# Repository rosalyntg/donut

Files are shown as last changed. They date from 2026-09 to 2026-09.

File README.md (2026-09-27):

# Donut

A simple ring light designed for a StereoZoom 4 microscope.

## Basic description

A ring light with adjustable brightness (potentiometer knob) driven by a MP3383 LED driver. It has 60 LEDs on them arranged in a circular pattern to give good lighting.

## Images

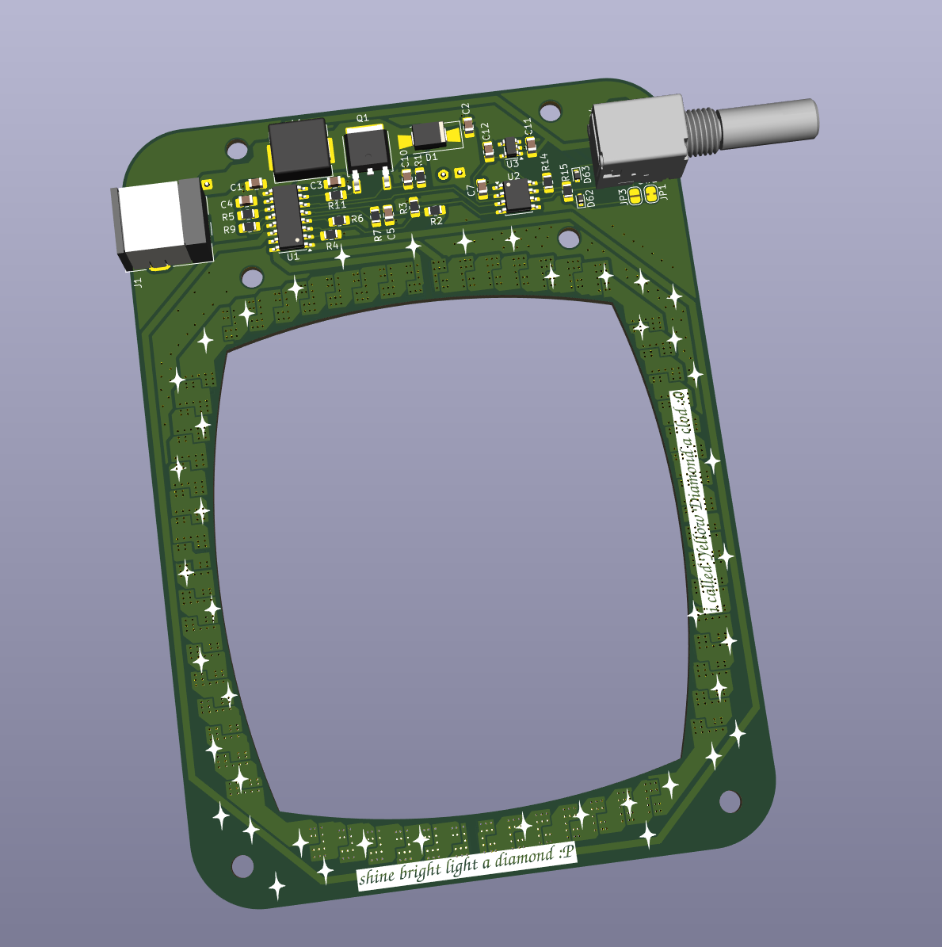
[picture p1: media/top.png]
Donut Top Ring Light

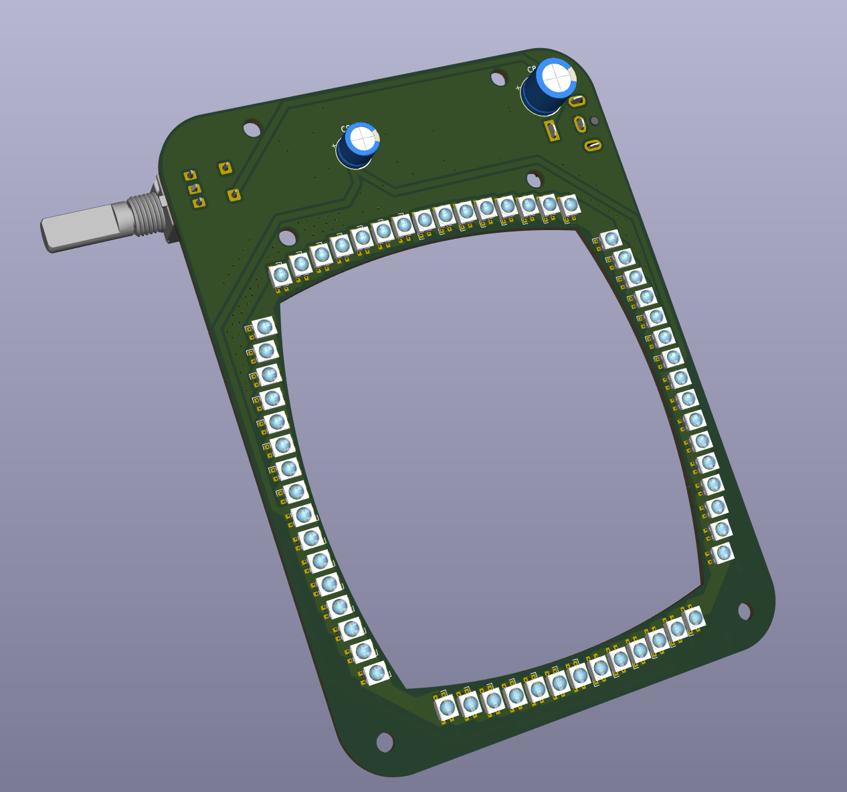
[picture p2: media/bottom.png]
Donut Bottom Ring Light


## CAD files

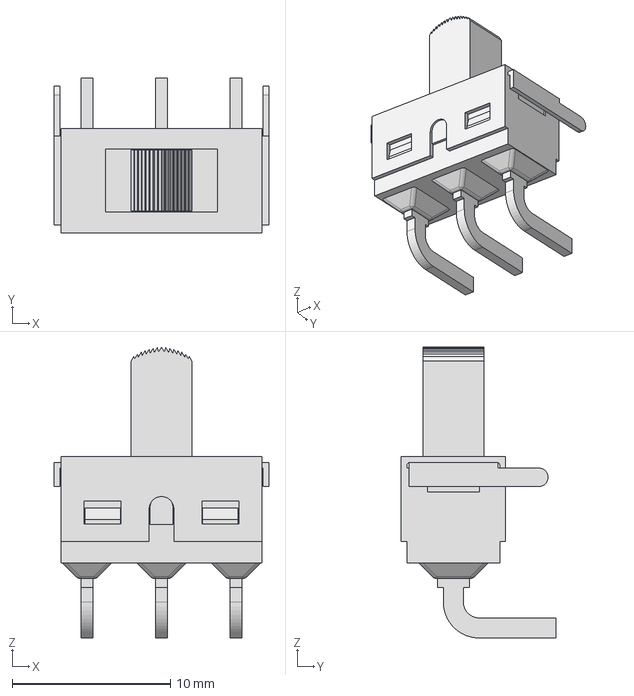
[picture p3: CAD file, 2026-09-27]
3d/141_500SSPxS2M6xEA.stp
13.6 x 9.78 x 18.4 mm

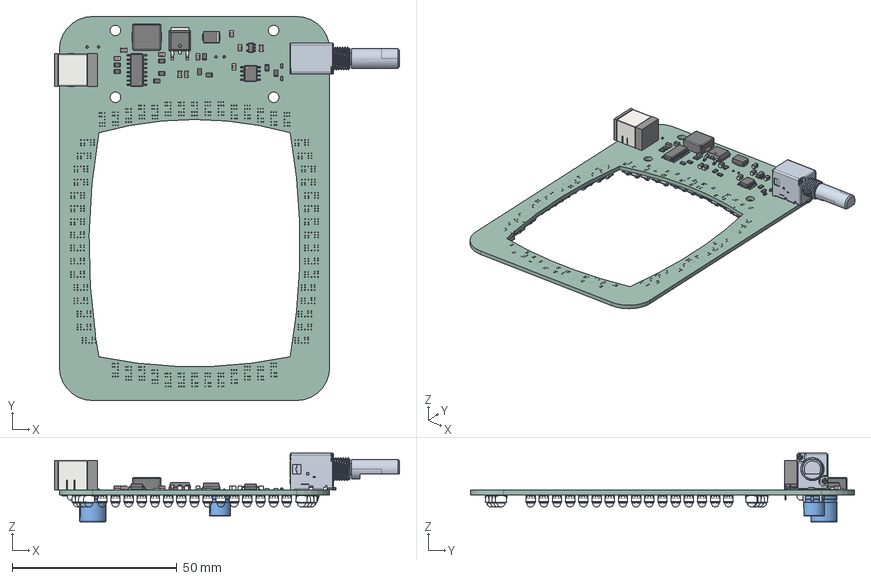
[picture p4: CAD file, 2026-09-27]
donut/donut.step
104.7 x 116.5 x 20.8 mm
R_0805_2012Metric x 10
SOT-23-5
932d09b3-9c39-11ed-93f0-dde97e994e83_part
932d09b4-9c39-11ed-93f0-dde97e994e83_part
932d09b5-9c39-11ed-93f0-dde97e994e83_part
BarrelJack_CUI_PJ-063AH_Horizontal
C_0805_2012Metric x 10
L_APV_APH0840
P091S-FC20_SW0001
D_SOD_523 x 2
SOIC-8_3.9x4.9mm_P1.27mm
D_SMB
SOIC-16_3.9x9.9mm_P1.27mm
IN-P36ATEUW.56 x 60
CP_Radial_D63mm_P250mm
CP_Radial_D80mm_P350mm
donut-unsaved-export-lDOu0E_PCB

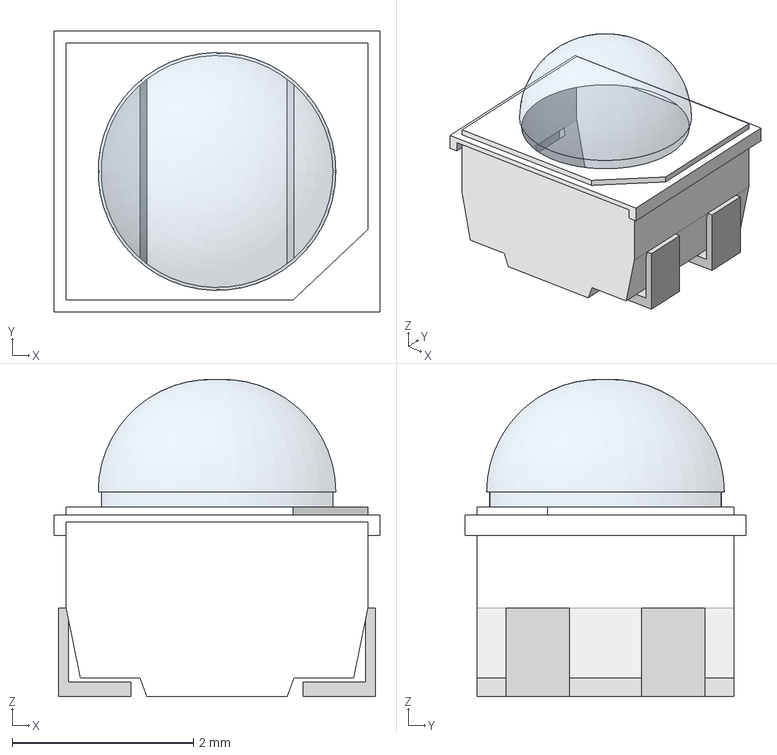
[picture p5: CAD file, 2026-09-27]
3d/IN-P36ATEUW.56.stp
3.60 x 3.10 x 3.50 mm

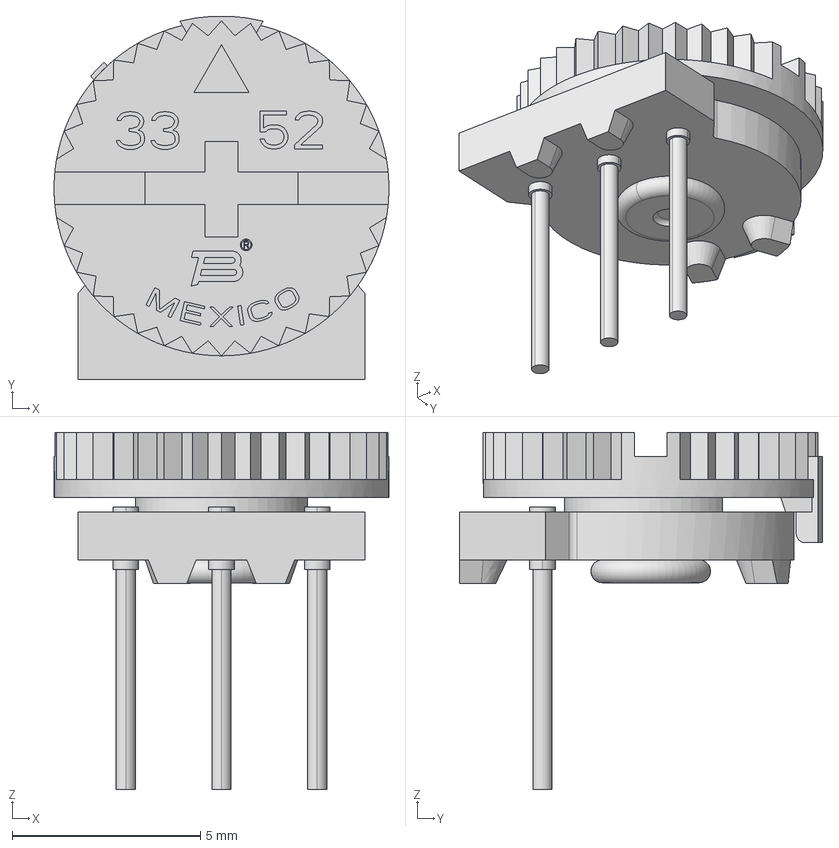
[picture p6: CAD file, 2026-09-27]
3d/3352T-1.stp
8.89 x 9.65 x 9.47 mm

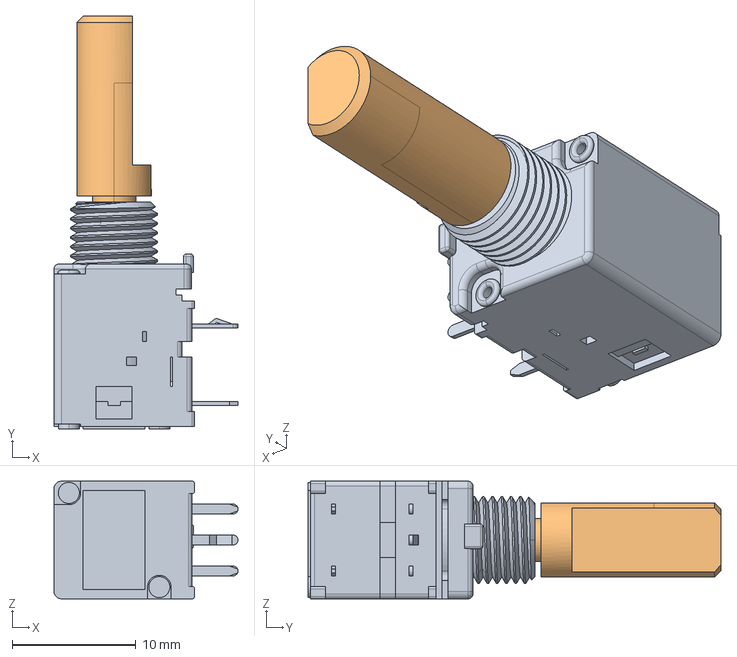
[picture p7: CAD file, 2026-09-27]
3d/P091S-FC20BR10K.stp
14.9 x 33.3 x 9.50 mm

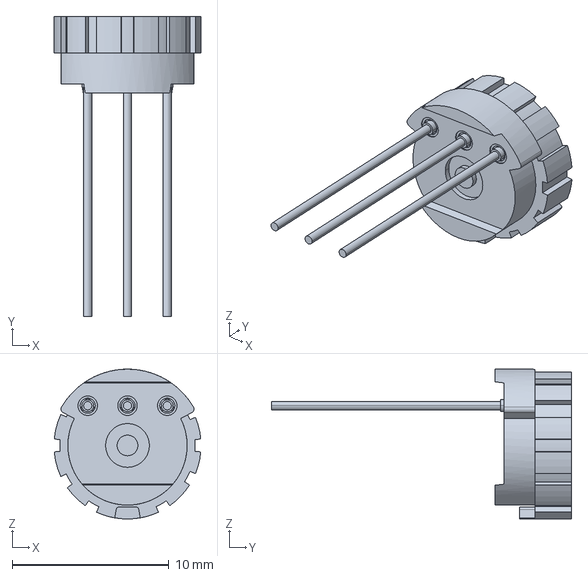
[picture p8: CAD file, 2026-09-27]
3d/TT-91A.stp
9.36 x 19.2 x 9.57 mm

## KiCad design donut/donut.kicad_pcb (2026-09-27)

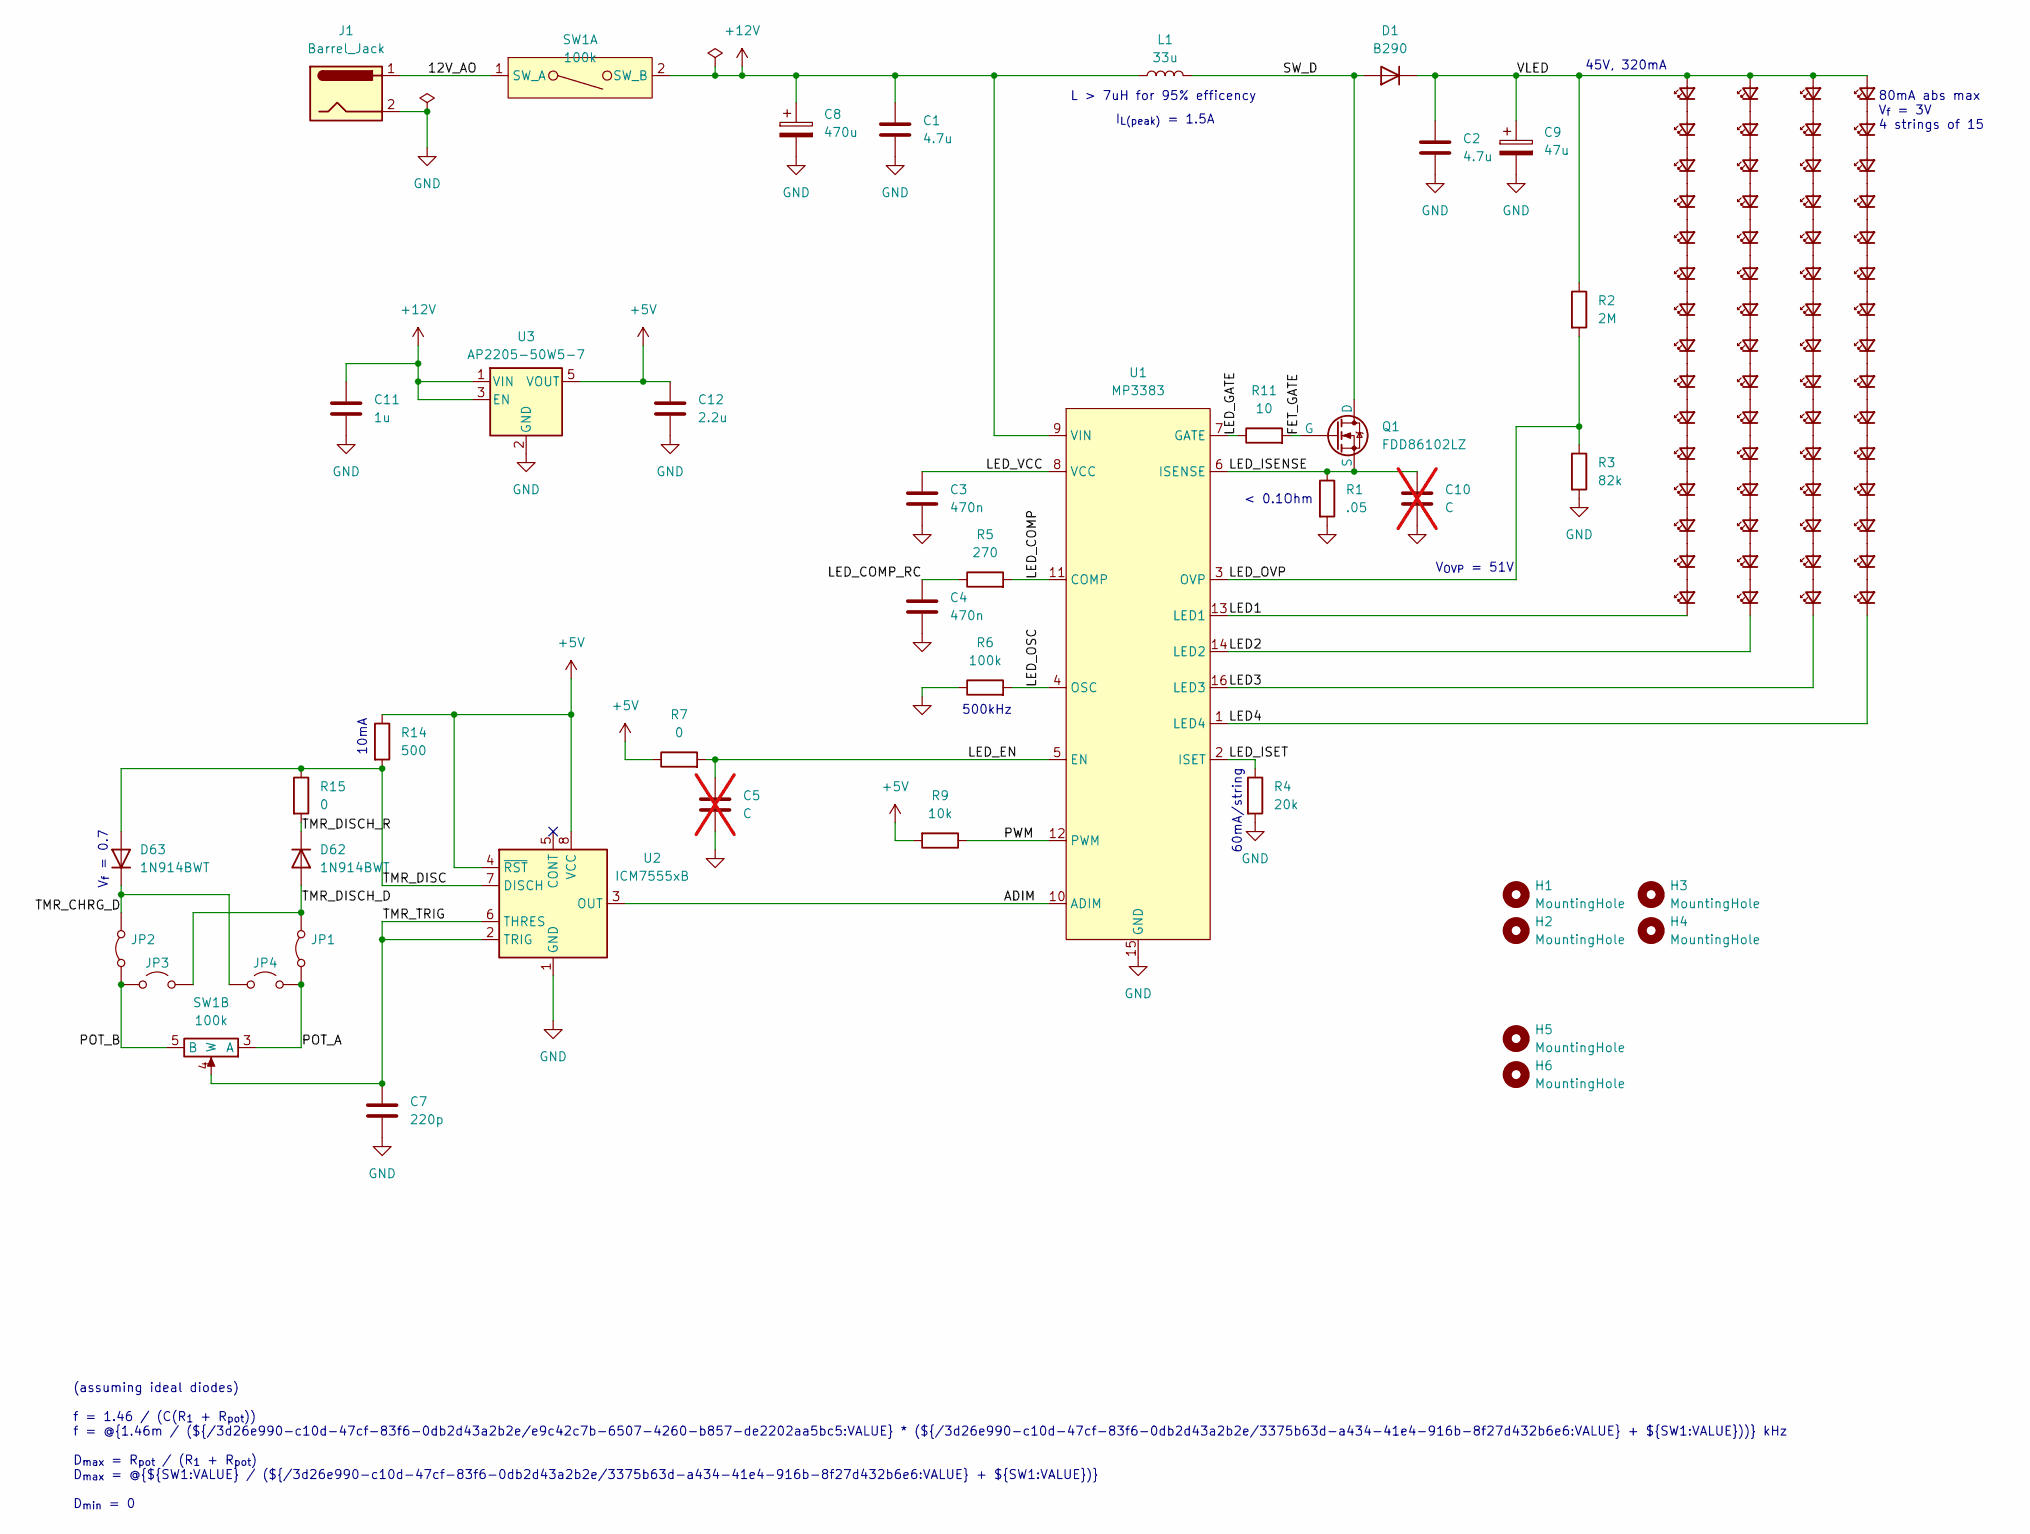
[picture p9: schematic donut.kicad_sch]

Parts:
C1, C2: 4.7u; C_0805_2012Metric_Pad1.18x1.45mm_HandSolder; Manufacturer Part Number GRT21BR61H475KE13L; Digikey Part Number 490-12394-1-ND
C3, C4: 470n; C_0805_2012Metric_Pad1.18x1.45mm_HandSolder
C5, C10: C; C_0805_2012Metric_Pad1.18x1.45mm_HandSolder; not fitted
C7: 220p; C_0805_2012Metric_Pad1.18x1.45mm_HandSolder
C8: 470u; CP_Radial_D8.0mm_P3.50mm; Manufacturer Part Number 860020374012; Digikey Part Number 732-8799-1-ND
C9: 47u; CP_Radial_D6.3mm_P2.50mm; Manufacturer Part Number 860020773013; Digikey Part Number 732-8974-1-ND
C11: 1u; C_0805_2012Metric_Pad1.18x1.45mm_HandSolder; Manufacturer Part Number GRM21BR71A10KA01L
C12: 2.2u; C_0805_2012Metric_Pad1.18x1.45mm_HandSolder; Manufacturer Part Number GRM21BR71E225KE11K
D1: B290; D_SMA-SMB_Universal_Handsoldering; Manufacturer Part Number B290-13-F; Digikey Part Number B290-FDICT-ND
D2, D3, D4, D5, D6, D7, D8, D9, D10, D11, D12, D13, D14, D15, D16, D17, D18, D19, D20, D21, D22, D23, D24, D25, D26, D27, D28, D29, D30, D31, D32, D33, D34, D35, D36, D37, D38, D39, D40, D41, D42, D43, D44, D45, D46, D47, D48, D49, D50, D51, D52, D53, D54, D55, D56, D57, D58, D59, D60, D61: LED_Small; IN-P36ATEUW; Manufacturer Part Number IN-P36BTEUW.50; Digikey Part Number IN-P36BTEUW.50
D62, D63: 1N914BWT; D_SOD-523; Manufacturer Part Number 1N914BWT; Digikey Part Number 1N914BWTCT-ND
H1, H2, H3, H4, H5, H6: MountingHole; MountingHole_3.2mm_M3
J1: Barrel_Jack; BarrelJack_CUI_PJ-063AH_Horizontal; Manufacturer Part Number PJ-063AH; Digikey Part Number CP-063AH-ND
JP1, JP2: Jumper_2_Bridged; SolderJumper-2_P1.3mm_Bridged_RoundedPad1.0x1.5mm
JP3, JP4: Jumper_2_Open; SolderJumper-2_P1.3mm_Open_RoundedPad1.0x1.5mm
L1: 33u; L_APV_APH0840; Manufacturer Part Number PA5449.333NLT; Digikey Part Number 553-PA5449.333NLTCT-ND
Q1: FDD86102LZ; TO-252-2_TabPin1; Manufacturer Part Number FDD86102LZ; Digikey Part Number FDD86102LZFSCT-ND
R1: .05; R_0805_2012Metric_Pad1.20x1.40mm_HandSolder; Manufacturer Part Number RL1220T-R050-G; Digikey Part Number RL12T.05GCT-ND
R2: 2M; R_0805_2012Metric_Pad1.20x1.40mm_HandSolder
R3: 82k; R_0805_2012Metric_Pad1.20x1.40mm_HandSolder
R4: 20k; R_0805_2012Metric_Pad1.20x1.40mm_HandSolder
R5: 270; R_0805_2012Metric_Pad1.20x1.40mm_HandSolder
R6: 100k; R_0805_2012Metric_Pad1.20x1.40mm_HandSolder
R7, R15: 0; R_0805_2012Metric_Pad1.20x1.40mm_HandSolder
R9: 10k; R_0805_2012Metric_Pad1.20x1.40mm_HandSolder
R11: 10; R_0805_2012Metric_Pad1.20x1.40mm_HandSolder
R14: 500; R_0805_2012Metric_Pad1.20x1.40mm_HandSolder
SW1: 100k; Potentiometer_P091S; Manufacturer Part Number P091S-FC20BR10K; Digikey Part Number 987-1283-ND
U1: MP3383; SOIC-16_3.9x9.9mm_P1.27mm; Manufacturer Part Number MP3383GS-P; Digikey Part Number 1589-MP3383GS-PCT-ND
U2: ICM7555xB; SOIC-8_3.9x4.9mm_P1.27mm; Manufacturer Part Number ICM7555CBAZ-T; Digikey Part Number ICM7555CBAZ-TCT-ND
U3: AP2205-50W5-7; SOT-23-5; Manufacturer Part Number AP2205-50W5-7; Digikey Part Number 31-AP2205-50W5-7CT-ND

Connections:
+5V: C12.1, R7.1, R9.2, R14.1, U2.4 (~RST), U2.8 (VCC), U3.5 (VOUT)
+12V: C1.1, C8.1, C11.1, L1.1, SW1.2 (SW_B), U1.9 (VIN), U3.1 (VIN), U3.3 (EN)
/12V_AO: J1.1, SW1.1 (SW_A)
/ADIM: U1.10 (ADIM), U2.3 (OUT)
/FET_GATE: Q1.2 (G), R11.2
/LED1: D46.1 (K), U1.13 (LED1)
/LED2: D31.1 (K), U1.14 (LED2)
/LED3: D2.1 (K), U1.16 (LED3)
/LED4: D61.1 (K), U1.1 (LED4)
/LED_COMP: R5.2, U1.11 (COMP)
/LED_COMP_RC: C4.1, R5.1
/LED_EN: C5.1, R7.2, U1.5 (EN)
/LED_GATE: R11.1, U1.7 (GATE)
/LED_ISENSE: C10.1, Q1.3 (S), R1.1, U1.6 (ISENSE)
/LED_ISET: R4.1, U1.2 (ISET)
/LED_OSC: R6.2, U1.4 (OSC)
/LED_OVP: R2.2, R3.1, U1.3 (OVP)
/LED_VCC: C3.1, U1.8 (VCC)
/POT_A: JP1.1 (A), JP4.2 (B), SW1.3 (A)
/POT_B: JP2.1 (A), JP3.1 (A), SW1.5 (B)
/PWM: R9.1, U1.12 (PWM)
/SW_D: D1.2 (A), L1.2, Q1.1 (D)
/TMR_CHRG_D: D63.1 (K), JP2.2 (B), JP4.1 (A)
/TMR_DISC: D63.2 (A), R14.2, R15.1, U2.7 (DISCH)
/TMR_DISCH_D: D62.2 (A), JP1.2 (B), JP3.2 (B)
/TMR_DISCH_R: D62.1 (K), R15.2
/TMR_TRIG: C7.1, SW1.4 (W), U2.2 (TRIG), U2.6 (THRES)
/VLED: C2.1, C9.1, D1.1 (K), D16.2 (A), D17.2 (A), D32.2 (A), D47.2 (A), R2.1
GND: C1.2, C2.2, C3.2, C4.2, C5.2, C7.2, C8.2, C9.2, C10.2, C11.2, C12.2, J1.2, R1.2, R3.2, R4.2, R6.1, U1.15 (GND), U2.1 (GND), U3.2 (GND)
unnamed: D2.2 (A), D3.1 (K)
unnamed: D3.2 (A), D4.1 (K)
unnamed: D4.2 (A), D5.1 (K)
unnamed: D5.2 (A), D6.1 (K)
unnamed: D6.2 (A), D7.1 (K)
unnamed: D7.2 (A), D8.1 (K)
unnamed: D8.2 (A), D9.1 (K)
unnamed: D10.2 (A), D11.1 (K)
unnamed: D9.2 (A), D10.1 (K)
unnamed: D11.2 (A), D12.1 (K)
unnamed: D12.2 (A), D13.1 (K)
unnamed: D13.2 (A), D14.1 (K)
unnamed: D14.2 (A), D15.1 (K)
unnamed: D15.2 (A), D16.1 (K)
unnamed: D17.1 (K), D18.2 (A)
unnamed: D18.1 (K), D19.2 (A)
unnamed: D19.1 (K), D20.2 (A)
unnamed: D20.1 (K), D21.2 (A)
unnamed: D21.1 (K), D22.2 (A)
unnamed: D22.1 (K), D23.2 (A)
unnamed: D23.1 (K), D24.2 (A)
unnamed: D24.1 (K), D25.2 (A)
unnamed: D25.1 (K), D26.2 (A)
unnamed: D26.1 (K), D27.2 (A)
unnamed: D27.1 (K), D28.2 (A)
unnamed: D28.1 (K), D29.2 (A)
unnamed: D29.1 (K), D30.2 (A)
unnamed: D30.1 (K), D31.2 (A)
unnamed: D32.1 (K), D33.2 (A)
unnamed: D33.1 (K), D34.2 (A)
unnamed: D34.1 (K), D35.2 (A)
unnamed: D35.1 (K), D36.2 (A)
unnamed: D36.1 (K), D37.2 (A)
unnamed: D37.1 (K), D38.2 (A)
unnamed: D38.1 (K), D39.2 (A)
unnamed: D39.1 (K), D40.2 (A)
unnamed: D40.1 (K), D41.2 (A)
unnamed: D41.1 (K), D42.2 (A)
unnamed: D42.1 (K), D43.2 (A)
unnamed: D43.1 (K), D44.2 (A)
unnamed: D44.1 (K), D45.2 (A)
unnamed: D45.1 (K), D46.2 (A)
unnamed: D47.1 (K), D48.2 (A)
unnamed: D48.1 (K), D49.2 (A)
unnamed: D49.1 (K), D50.2 (A)
unnamed: D50.1 (K), D51.2 (A)
unnamed: D51.1 (K), D52.2 (A)
unnamed: D52.1 (K), D53.2 (A)
unnamed: D53.1 (K), D54.2 (A)
unnamed: D54.1 (K), D55.2 (A)
unnamed: D55.1 (K), D56.2 (A)
unnamed: D56.1 (K), D57.2 (A)
unnamed: D57.1 (K), D58.2 (A)
unnamed: D58.1 (K), D59.2 (A)
unnamed: D59.1 (K), D60.2 (A)
unnamed: D60.1 (K), D61.2 (A)

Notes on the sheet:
V_{OVP} = 51V
45V, 320mA
I_{L(peak)} = 1.5A
< 0.1Ohm
(assuming ideal diodes) f = 1.46 / (C(R_{1} + R_{pot})) f = @{1.46m / (${/3d26e990-c10d-47cf-83f6-0db2d43a2b2e/e9c42c7b-6507-4260-b857-de2202aa5bc5:VALUE} * (${/3d26e990-c10d-47cf-83f6-0db2d43a2b2e/3375b63d-a434-41e4-916b-8f27d432b6e6:VALUE} + ${SW1:VALUE}))} kHz D_{max} = R_{pot} / (R_{1} + R_{pot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
L > 7uH for 95% efficency
V_{f} = 0.7
80mA abs max V_{f} = 3V 4 strings of 15
10mA
60mA/string
500kHz

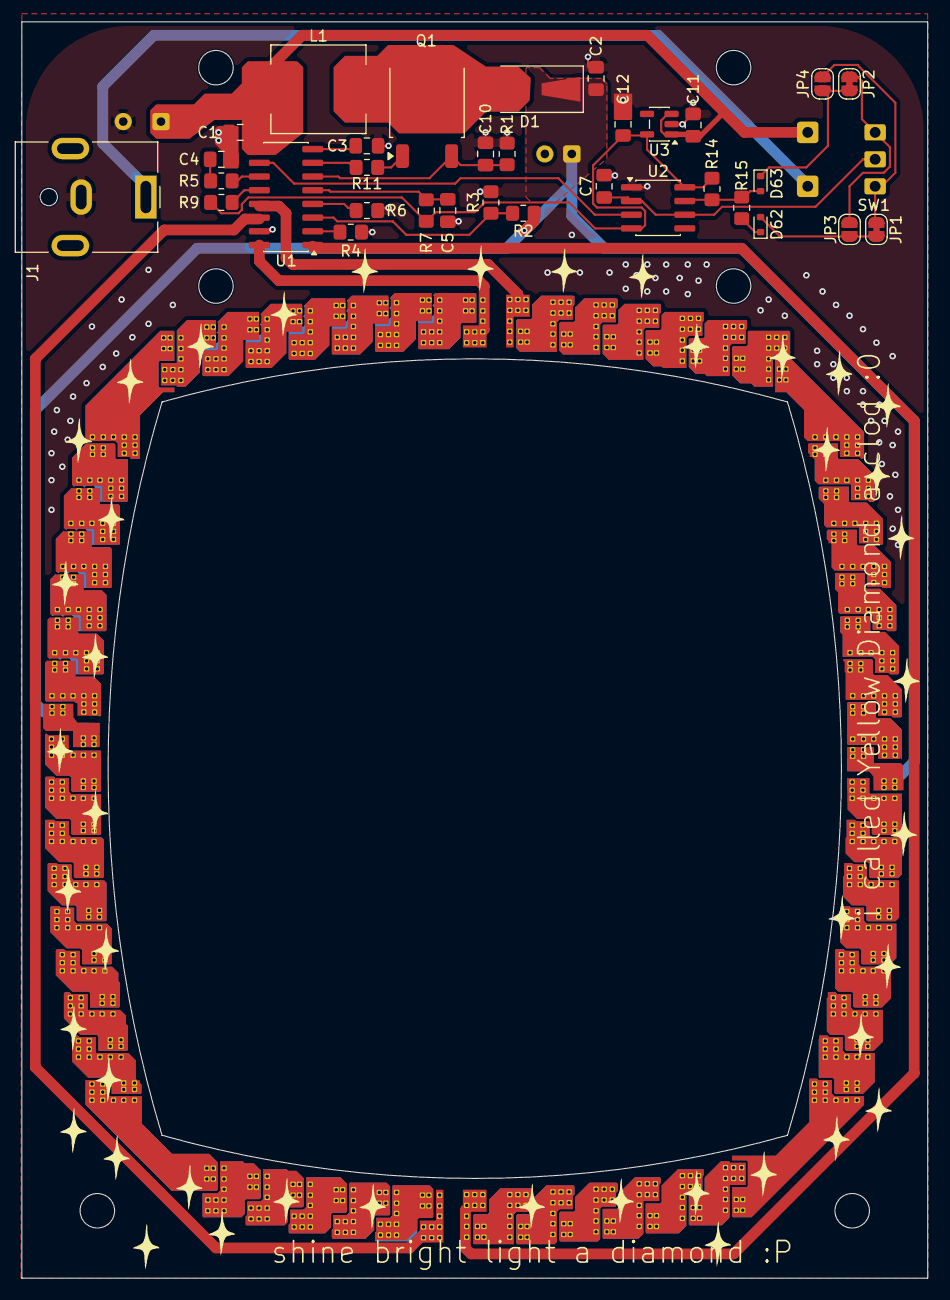
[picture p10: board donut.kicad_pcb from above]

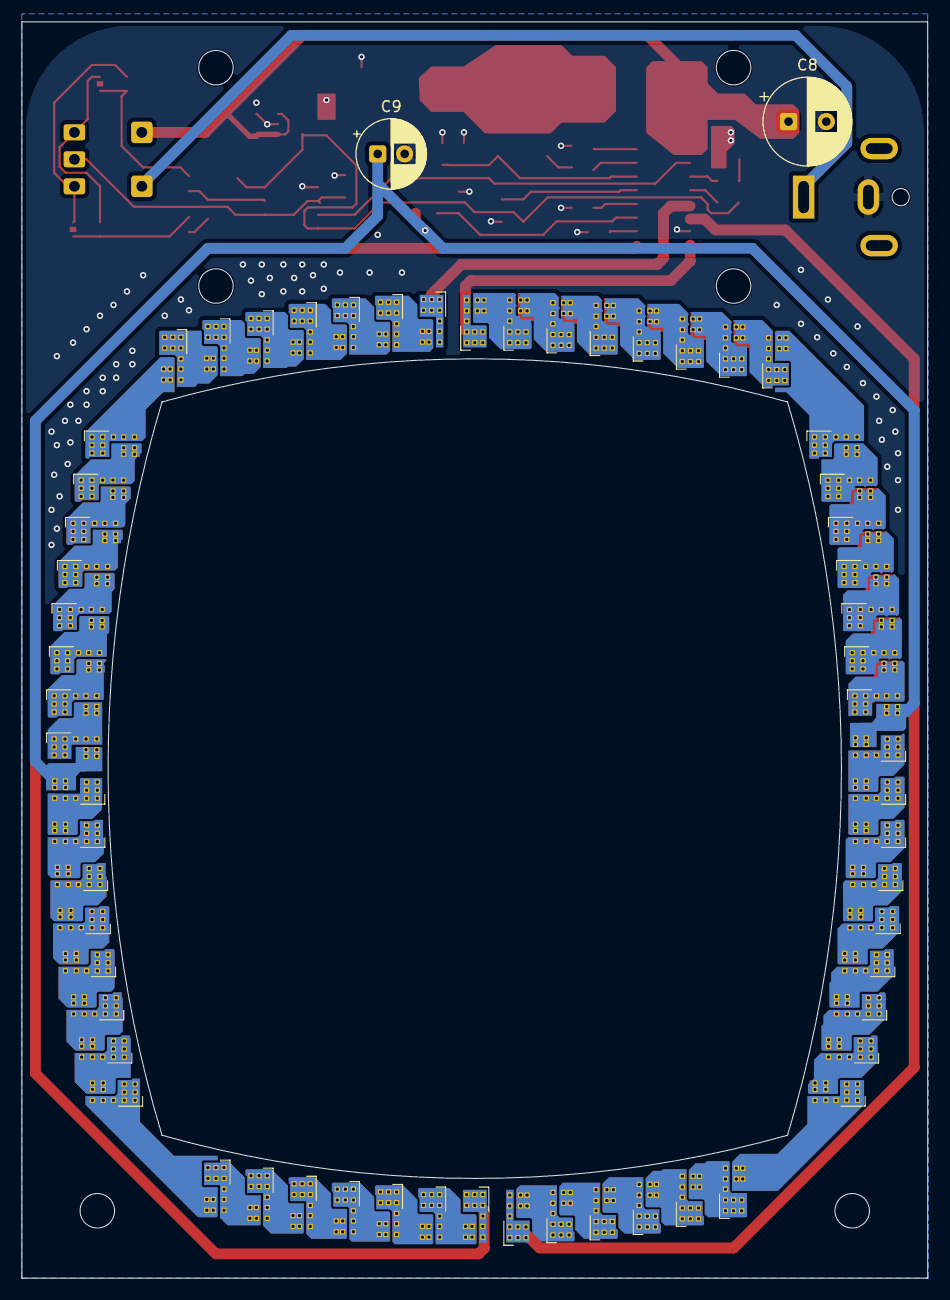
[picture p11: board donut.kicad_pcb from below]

Board: 2 copper layers, 84.0 x 116.5 mm, 102 parts (62 on the bottom side), 85 nets.

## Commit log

2026-09-27 source dump
    [141_500SSPxS2M6xEA.stp, 3352T-1.stp, IN-P36ATEUW.56.stp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]
2026-09-27 readme & library fixes
    [donut.kicad_pcb]
